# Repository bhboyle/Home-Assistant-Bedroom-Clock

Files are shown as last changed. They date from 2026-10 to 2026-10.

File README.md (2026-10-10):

Day Mode
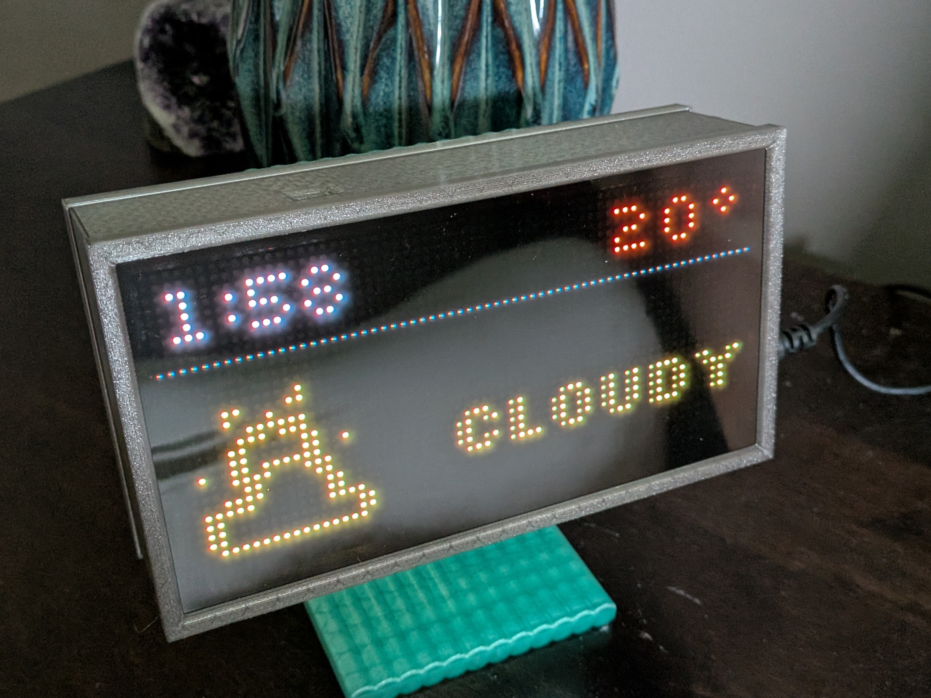
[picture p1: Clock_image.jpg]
Clock Picture


Night Mode
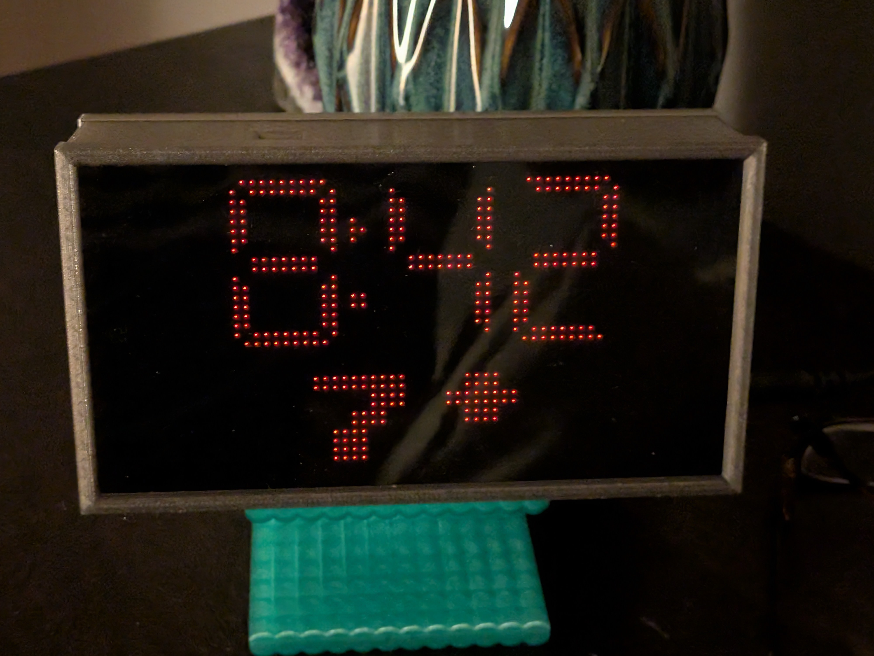
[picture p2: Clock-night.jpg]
Clock Picture


# Home Assistant Bedroom Clock
Bedroom Clock that displays time and weather data directly driven from Home Assistant. 

I should note that the ESPhome Yaml was created with the asistance of Claude

This clock uses a BH1750 to detect the ambiant light level in the room and has two modes based on the brightness in the room. A day time mode and a night time mode. In night mode it only displays the time and the temperature. The temperature in my case come from my weather station outside but of course this can be driven by any soruce in your HA ecosystem. In day time mode it displays the time, temperature and the weather data from what ever weather entities you have avilable. In my case I use Environment Canada. 

The housing is modeled in Fusion. The back and ND film holder both are a friction fit and stay in place well enough. The ND film helps bring the brightness down if you think the lowest intensity is too bright. Im told it also make the device look more proffesional.

The display is a 64x32 RGB matrix Purchased from [Amazon](https://www.amazon.ca/dp/B0BR7WTW2G?ref_=ppx_hzod_title_dt_b_fed_asin_title_0_0&th=1).

The driver board is a ESP#@ matrix driver board also purchaed from [Amazon](https://www.amazon.ca/dp/B0GYDMQKGN?ref_=pe_125682630_1045605200_t_fed_asin_title).

The Light sensor is also from [amazon](https://www.amazon.ca/dp/B0DDCD3VZC?ref=ppx_yo2ov_dt_b_fed_asin_title)

I used a font that I had to download. The font for the night mode comes from [here](https://www.keshikan.net/fonts-e.html). You have to download and extract DSEG7ClassicMini-Bold.ttf. Create a "fonts" folder under your "esphome" fonteron your Home Assistant instance. Copy the DSEG7ClassicMini-Bold.ttf font into this folder befoe compiling anf flashing.

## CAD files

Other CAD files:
Bedroom Clock.f3d

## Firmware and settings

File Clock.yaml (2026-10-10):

# Board: Adafruit MatrixPortal ESP32-S3
# Definition: definitions/boards/adafruit_matrixportal_esp32s3/manifest.yaml


esphome:
  name: bedroom-clock
  friendly_name: Bedroom Clock
  on_boot:
    priority: -100
    then:
      - script.execute: seed_default_colors
      - script.execute: apply_brightness

esp32:
  board: adafruit_matrixportal_esp32s3
  variant: esp32s3
  flash_size: 8MB
  framework:
    type: esp-idf

logger:
  level: INFO

api:
  encryption:
    key: "oy492MQXQF0VmmXXcxWOmj1ZpXZt7blaRHYc9UK0vKc="

# Without this you can only update over USB. Delete if that's intentional.
ota:
  - platform: esphome
    password: "qxrlmWl0i5TW"

wifi:
  ssid: !secret wifi_ssid
  password: !secret wifi_password
  ap:
    ssid: Bedroom Clock Fallback Hotspot
    password: "qxrlmWl0i5TW"

captive_portal:
####################################################################
# Adaptive Matrix Clock
#   Adafruit Matrix Portal S3 + 64x32 HUB75 panel + BH1750
#
#   Dark mode  : big time, big feels-like temp
#   Light mode : small time + temp, weather icon, scrolling condition
#   Test mode  : bypasses both, for confirming the panel works
#
#   HA controls: Dark Threshold, Light Threshold,
#                Dark Brightness, Light Brightness,
#                5 colour pickers, Test Message,
#                Display Test Mode / Display Test (15s)
####################################################################

substitutions:
  # Entities pulled from Home Assistant
  feels_like_entity: sensor.weather_station_feels_like_temperature
  condition_entity:  sensor.kingston_current_condition
  weather_entity:    weather.kingston_forecast


# The MatrixPortal S3 has 2MB of quad PSRAM. Not required for a 64x32
# panel, but harmless and useful if you later add images.
psram:
  mode: quad
  speed: 80MHz




time:
  - platform: homeassistant
    id: ha_time

####################################################################
# I2C + ambient light sensor
####################################################################

# STEMMA QT on the MatrixPortal S3. If the BH1750 isn't found, check
# the "Found i2c device at address 0x23" line in the boot log and
# adjust these two pins.
i2c:
  sda: GPIO16
  scl: GPIO17
  scan: true

####################################################################
# Globals
####################################################################

globals:
  - id: is_dark
    type: bool
    restore_value: true
    initial_value: 'true'

  - id: scroll_offset
    type: int
    restore_value: false
    initial_value: '0'

  # Used to seed sensible default colours on very first boot only
  - id: colors_initialized
    type: bool
    restore_value: true
    initial_value: 'false'

  # Tracks a mode flip that is waiting out the dwell timer
  - id: pending_active
    type: bool
    restore_value: false
    initial_value: 'false'
  - id: pending_dark
    type: bool
    restore_value: false
    initial_value: 'false'
  - id: pending_since
    type: uint32_t
    restore_value: false
    initial_value: '0'

####################################################################
# HA-facing controls (these appear automatically as sliders)
####################################################################

number:
  - platform: template
    name: "Dark Threshold"
    id: dark_threshold
    icon: mdi:weather-night
    entity_category: config
    optimistic: true
    restore_value: true
    initial_value: 15
    min_value: 0
    max_value: 300
    step: 1
    unit_of_measurement: "lx"
    # box = typed number input. A slider over a 0-1000 lux
    # range can't resolve single lux values by dragging.
    mode: box

  - platform: template
    name: "Light Threshold"
    id: light_threshold
    icon: mdi:white-balance-sunny
    entity_category: config
    optimistic: true
    restore_value: true
    initial_value: 45
    min_value: 0
    max_value: 1000
    step: 1
    unit_of_measurement: "lx"
    # box = typed number input. A slider over a 0-1000 lux
    # range can't resolve single lux values by dragging.
    mode: box

  - platform: template
    name: "Mode Switch Delay"
    id: switch_delay
    icon: mdi:timer-sand
    entity_category: config
    optimistic: true
    restore_value: true
    initial_value: 10
    min_value: 0
    max_value: 300
    step: 1
    unit_of_measurement: "s"
    mode: slider

  - platform: template
    name: "Dark Mode Brightness"
    id: dark_brightness
    icon: mdi:brightness-3
    entity_category: config
    optimistic: true
    restore_value: true
    initial_value: 12
    min_value: 1
    max_value: 100
    step: 1
    unit_of_measurement: "%"
    mode: slider
    on_value:
      - script.execute: apply_brightness
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
